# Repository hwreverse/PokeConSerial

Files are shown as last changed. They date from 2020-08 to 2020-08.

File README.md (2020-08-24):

# PokeConSerial
Serial Interfaces for Pocket Computers (ポケコン) (Sharp, Casio, TRS80-M100,...)<br>
(PCB Layouts are in KiCAD 5.1.6*)

- <a href="g850_kiss/">Sharp G800/G850/V/S/VS 11pin USB to Serial Interface</a>

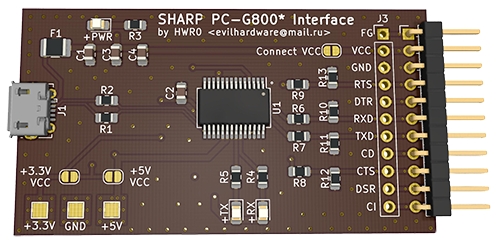
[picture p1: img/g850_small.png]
Sharp G850* USB to Serial Interface


- <a href="Sharp_11pin_to_15pin_Adapter/">Sharp 11pin to 15pin Adapter</a>
  (to use the Sharp G850* USB to Serial adapter with the Sharp PC-E500 and the Sharp PC-1600)
  
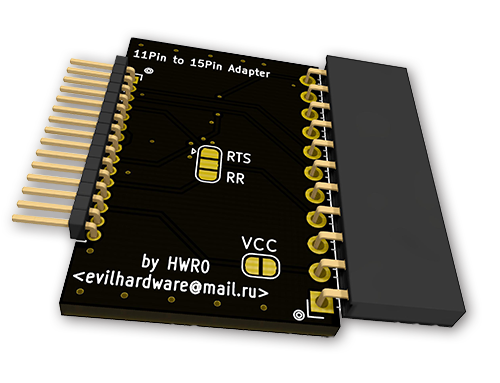
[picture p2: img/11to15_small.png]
Sharp 11pin to 15pin Adapter


- <a href="PC1600SIO/">Sharp PC-E500 / PC-1600 15pin USB to Serial Interface</a>
  
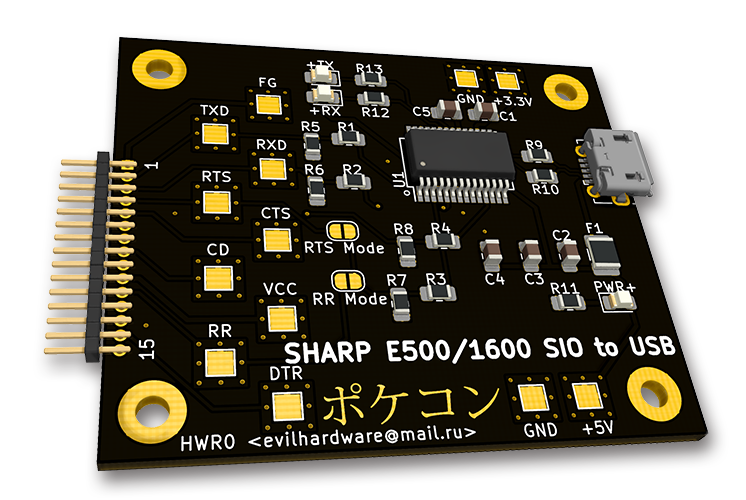
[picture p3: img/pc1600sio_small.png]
Sharp PC-E500 / PC-1600 15pin USB to Serial Interface


- Casio FA-7 compatible (for PB-1000, AI-1000, PB-2000C) USB Interface (soon, needs to be validated)

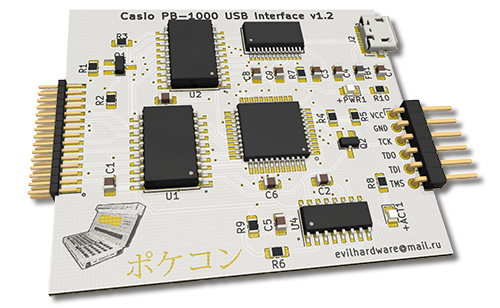
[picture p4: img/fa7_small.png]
Casio FA-7 compatible USB Interface


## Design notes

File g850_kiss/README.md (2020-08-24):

# SHARP PC-G800*/G850*/V/S/VS 11pin USB to Serial Interface
USB to Serial (FT232RL based) Interface for the SHARP G800* line of Pocket Computers (G811, G850, G850V, G850S, G850VS)

Sharp PC-G850* Adapter

## Important
NB1: the 11pin adapter is a 1x11 pin 2.54mm (100mil) male connector<br>
NB2: Use VCC Connect if for some reason, you want to power the device from USB (use with *EXTREME* care!!)<br>
NB3: Bridge the 5V VCCIO Solder Jumper to work with the G850*, this sets the I/O Level to 5V<br>

## Components

The USB-B-micro Receptacle in this schema is a Molex 105017-0001 / 105017-1001, every diode / R / C is 0805, FT232RL is a SSOP28, the Polyfuse is a 1210 500mA or similar

## After-Construction Configuration

As the Sharp Pocket computers use <b>inverted</b> Levels, you have to invert RXD, TXD, RTS# and CTS# on your FT232RL chip too.

You do this by downloading the program <b>FTProg</b> from the FTDI Site :  <a href="https://www.ftdichip.com/Support/Utilities.htm#FT_PROG">Here</a>.

You need also to configure CBUS0 as RXLED and CBUS1 as TXLED in order to gain LED Functionality.

<b> AND FOR HEAVENS' SAKE:</b> Never set the FT chip to External OSC (Escpecially on this board where it does not have an External Oscillator) lest you are self-destructive and want to brick your chip !

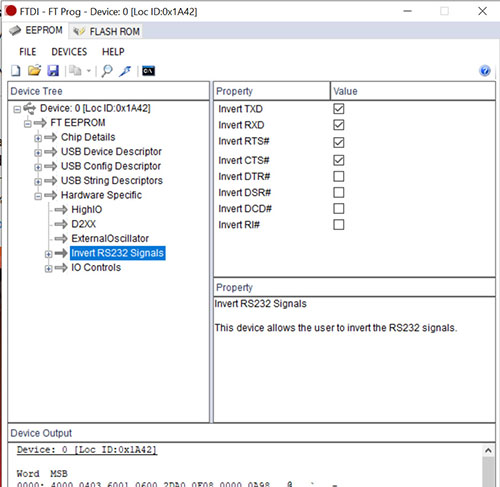
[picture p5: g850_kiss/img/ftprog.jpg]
ftprog


-------------------------

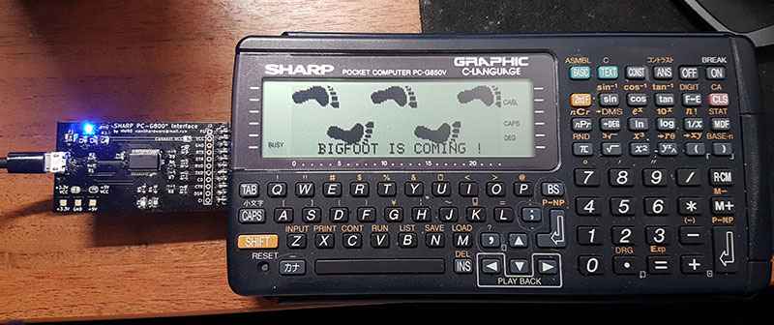
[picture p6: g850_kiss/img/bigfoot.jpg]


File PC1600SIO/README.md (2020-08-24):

# SHARP PC-E500/E500S/PC-1600/PC-1600K 15pin USB to Serial Interface
USB to Serial (FT232RL based) Interface for the SHARP PC-E500 / E500S / PC-1600 / PC-1600K line of Pocket Computers 

Sharp PC-E500/PC-1600 Adapter

## Important
NB 1: the 15pin adapter is a 1x15 pin 1.27mm (50mil) male connector<br>
NB 2: You have to bridge the right solderjumper (RR or RTS) depending on the mode you use for it to work. I have RTS bridged usually 

## Components

The USB-B-micro Receptacle in this schema is a Molex 105017-0001 / 105017-1001, every LED / R / L / C is 0805, FT232RL is a SSOP28, the Polyfuse is a 1210 PTC Resettable fuse, 500-700mA or similar

## After-Construction Configuration

As the Sharp Pocket computers use <b>inverted</b> Levels, you have to invert RXD, TXD, RTS# and CTS# on your FT232RL chip too.

You do this by downloading the program <b>FTProg</b> from the FTDI Site :  <a href="https://www.ftdichip.com/Support/Utilities.htm#FT_PROG">Here</a>.

You need also to configure CBUS0 as RXLED and CBUS1 as TXLED in order to gain LED Functionality.

<b> AND FOR HEAVEANS' SAKE:</b> Never set the FT chip to External OSC (Escpecially on this board where it does not have an External Oscillator) lest you are self-destructive and want to brick your chip !

ftprog

-------------------------

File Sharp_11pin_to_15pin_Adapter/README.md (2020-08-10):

# SHARP 11pin to 15pin Adapter
Adapter to use with the <a href="https://github.com/hwreverse/PokeConSerial/tree/master/g850_kiss">Sharp G800* USB to Serial Interface</a>
to make it work for the SHARP PC-E500 and the Sharp PC-1600

NB 1: the 11pin adapter is a 1x11 pin 2.54mm (100mil) female connector, the 15pin adaptor is a 1x15pin 1.27mm (50mil) male connector

NB 2: You have to bridge the right solderjumper (RR or RTS) depending on the mode you use for it to work. I use RTS with both calculators

NB 3: Use VCC Connect if for some reason, you want to power the device from USB (use with *EXTREME* care!!)

Sharp 11pin to 15pin adapter

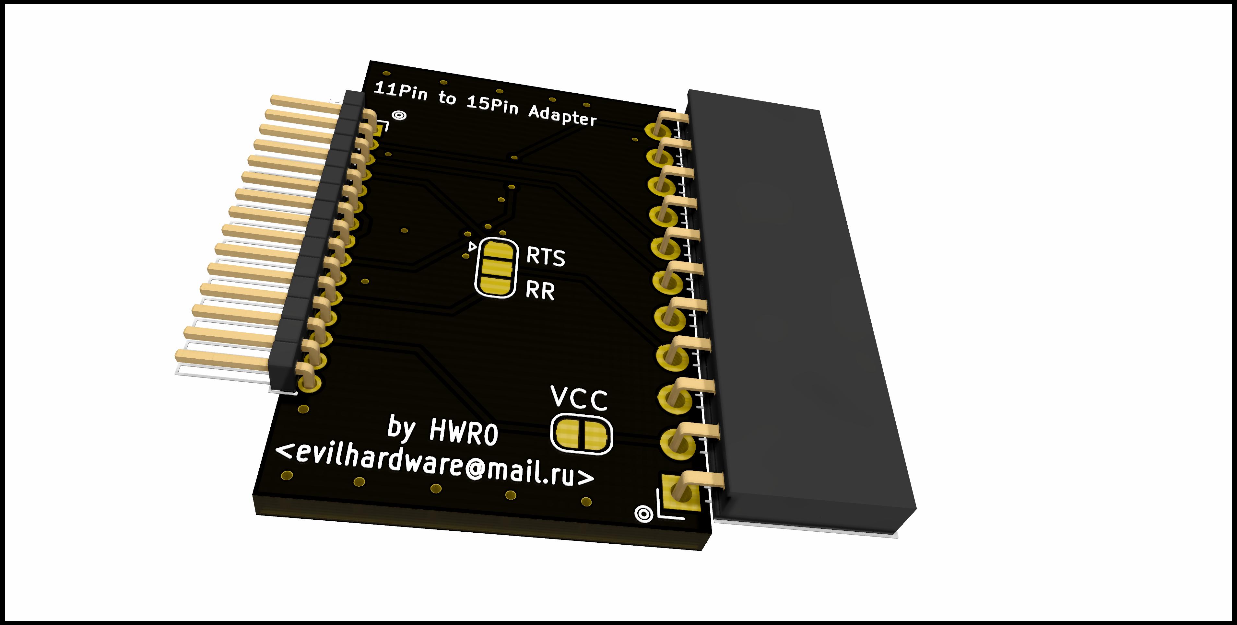
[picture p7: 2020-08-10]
Sharp_11pin_to_15pin_Adapter/Sharp_11pin_to_15pin_Adapter.jpg

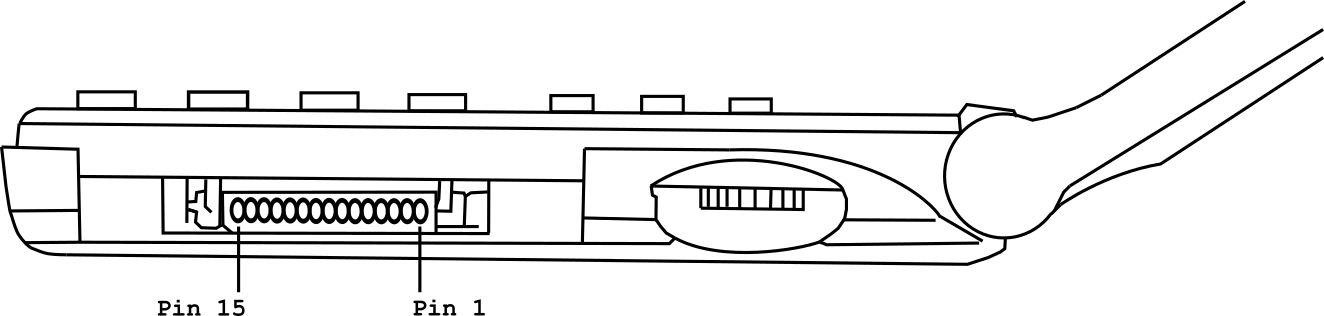
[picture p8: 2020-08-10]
PC1600SIO/e500sio.png

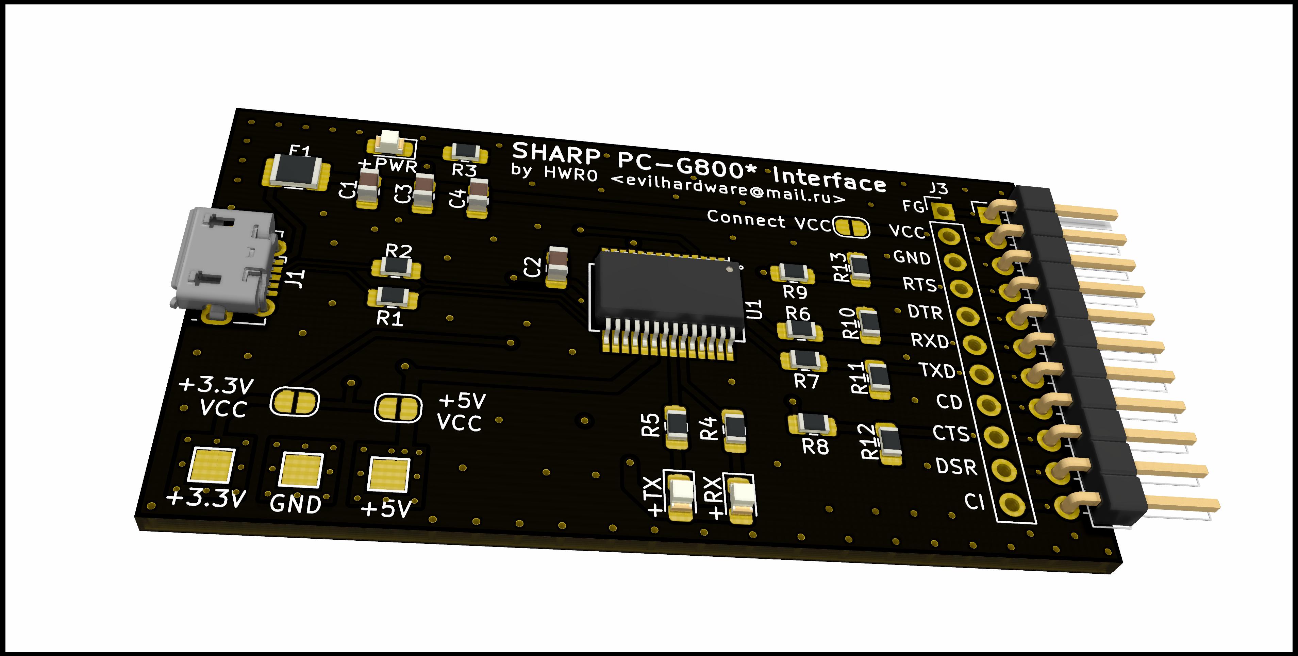
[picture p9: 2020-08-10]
g850_kiss/g850_kiss2.jpg

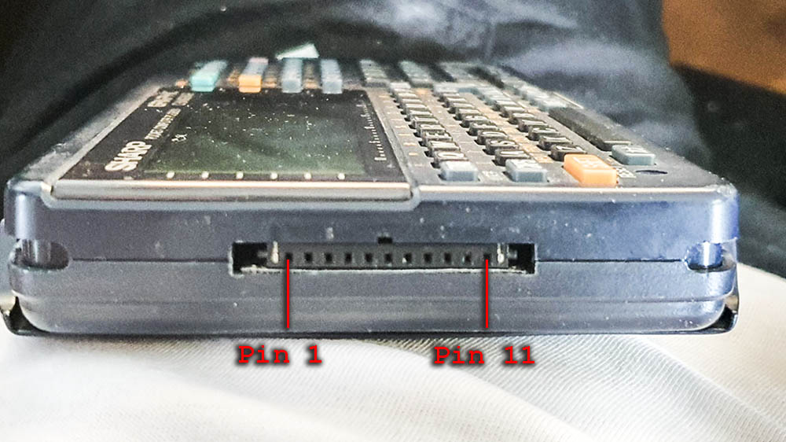
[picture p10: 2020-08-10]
g850_kiss/g850_11pin interface.jpg

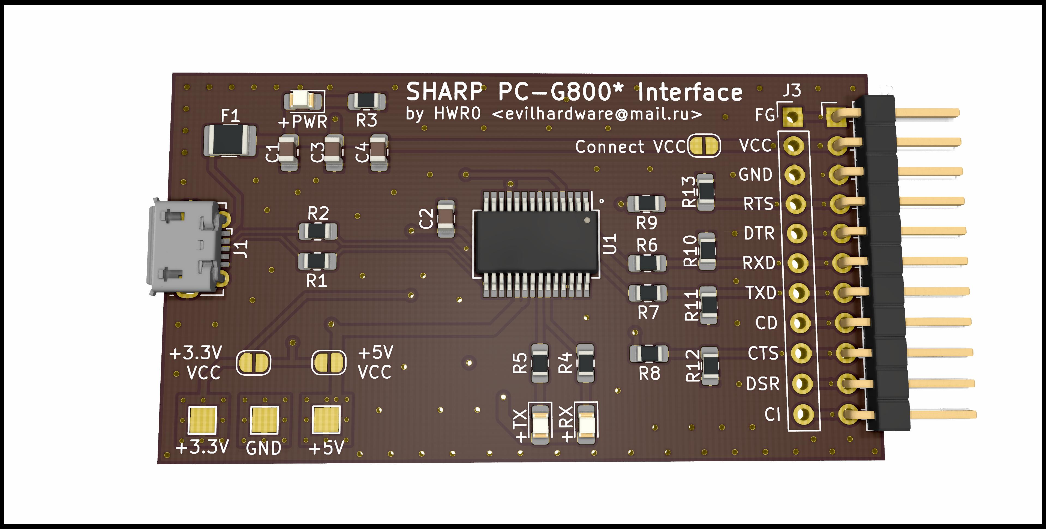
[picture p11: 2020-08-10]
g850_kiss/g850_kiss.jpg

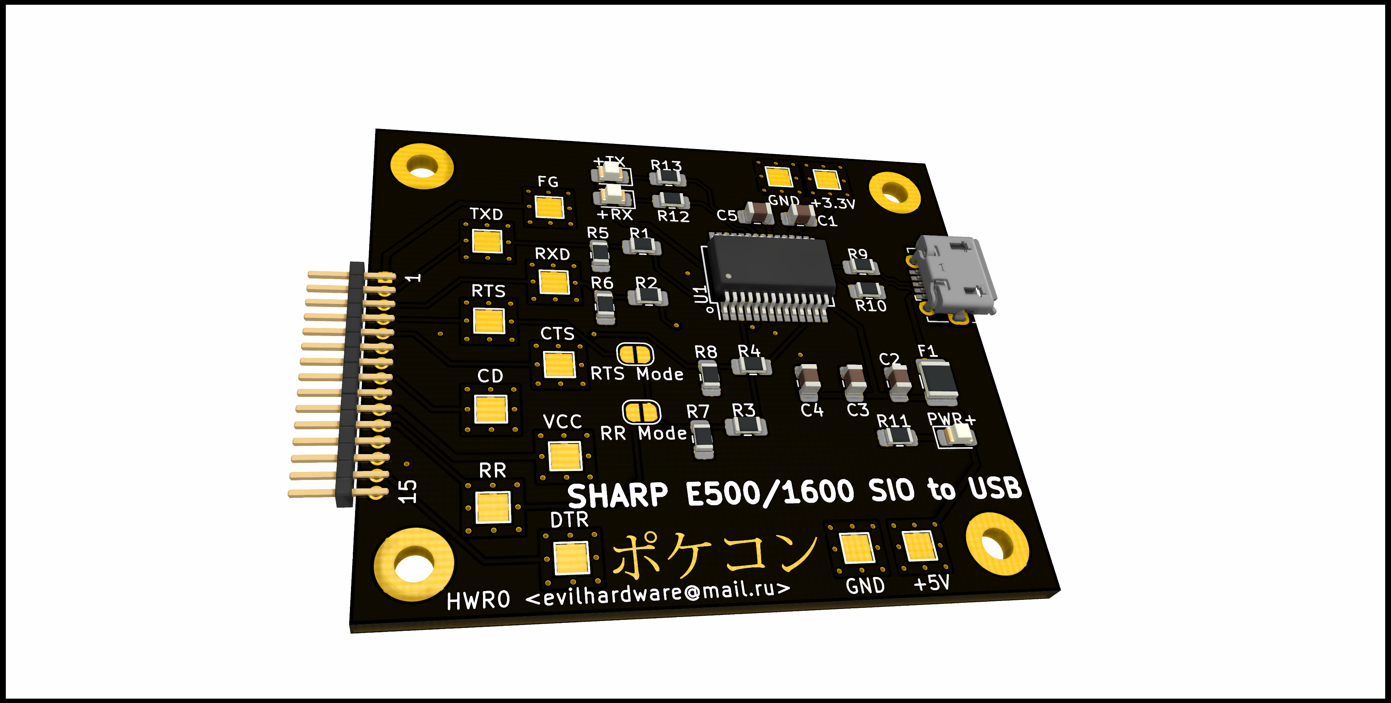
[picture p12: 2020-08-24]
PC1600SIO/PC1600SIO.png

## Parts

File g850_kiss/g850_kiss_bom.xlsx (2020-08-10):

Source: | O:\elec\g850_kiss\g850_kiss.sch
Date: | 2019-12-28 15:27
Tool: | Eeschema (5.1.5)-3
Component Count: | 28
Ref | Value | Footprint | Datasheet | Manufacturer | Vendor
C1 | 0.1uF | Capacitor_SMD:C_0805_2012Metric_Pad1.15x1.40mm_HandSolder | ~
C2 | 0.1uF | Capacitor_SMD:C_0805_2012Metric_Pad1.15x1.40mm_HandSolder | ~
C3 | 10nF | Capacitor_SMD:C_0805_2012Metric_Pad1.15x1.40mm_HandSolder | ~
C4 | 10nF | Capacitor_SMD:C_0805_2012Metric_Pad1.15x1.40mm_HandSolder | ~
D1 | PWRLED | LED_SMD:LED_0805_2012Metric_Pad1.15x1.40mm_HandSolder | ~
D2 | RX | LED_SMD:LED_0805_2012Metric_Pad1.15x1.40mm_HandSolder | ~
D3 | TX | LED_SMD:LED_0805_2012Metric_Pad1.15x1.40mm_HandSolder | ~
F1 | Polyfuse 1210 | Resistor_SMD:R_1210_3225Metric_Pad1.42x2.65mm_HandSolder | 500mA polyfuse (1210)
J1 | USB_B_Micro | hwreverse:USB_Micro-B_Molex-105017-0001 | Molex-105017-0001 USB micro
J2 | G850_Input_Connector | Connector_PinHeader_2.54mm:PinHeader_1x11_P2.54mm_Horizontal | ~
J3 | Dup_G850_Connector | Connector_PinHeader_2.54mm:PinHeader_1x11_P2.54mm_Vertical | ~
JP1 | SJ3V | Jumper:SolderJumper-2_P1.3mm_Open_RoundedPad1.0x1.5mm | ~
JP2 | SJ5V | Jumper:SolderJumper-2_P1.3mm_Open_RoundedPad1.0x1.5mm | ~
JP3 | SJPWRCalc | Jumper:SolderJumper-2_P1.3mm_Open_RoundedPad1.0x1.5mm | ~
R1 | 15R | Resistor_SMD:R_0805_2012Metric_Pad1.15x1.40mm_HandSolder | ~
R2 | 15R | Resistor_SMD:R_0805_2012Metric_Pad1.15x1.40mm_HandSolder | ~
R3 | 500R | Resistor_SMD:R_0805_2012Metric_Pad1.15x1.40mm_HandSolder | ~
R4 | 500R | Resistor_SMD:R_0805_2012Metric_Pad1.15x1.40mm_HandSolder | ~
R5 | 500R | Resistor_SMD:R_0805_2012Metric_Pad1.15x1.40mm_HandSolder | ~
R6 | 100R | Resistor_SMD:R_0805_2012Metric_Pad1.15x1.40mm_HandSolder | ~
R7 | 100R | Resistor_SMD:R_0805_2012Metric_Pad1.15x1.40mm_HandSolder | ~
R8 | 100R | Resistor_SMD:R_0805_2012Metric_Pad1.15x1.40mm_HandSolder | ~
R9 | 100R | Resistor_SMD:R_0805_2012Metric_Pad1.15x1.40mm_HandSolder | ~
R10 | 10K | Resistor_SMD:R_0805_2012Metric_Pad1.15x1.40mm_HandSolder | ~
R11 | 10K | Resistor_SMD:R_0805_2012Metric_Pad1.15x1.40mm_HandSolder | ~
R12 | 10K | Resistor_SMD:R_0805_2012Metric_Pad1.15x1.40mm_HandSolder | ~
R13 | 10K | Resistor_SMD:R_0805_2012Metric_Pad1.15x1.40mm_HandSolder | ~
U1 | FT232RL | Package_SO:SSOP-28_5.3x10.2mm_P0.65mm | https://www.ftdichip.com/Support/Documents/DataSheets/ICs/DS_FT232R.pdf

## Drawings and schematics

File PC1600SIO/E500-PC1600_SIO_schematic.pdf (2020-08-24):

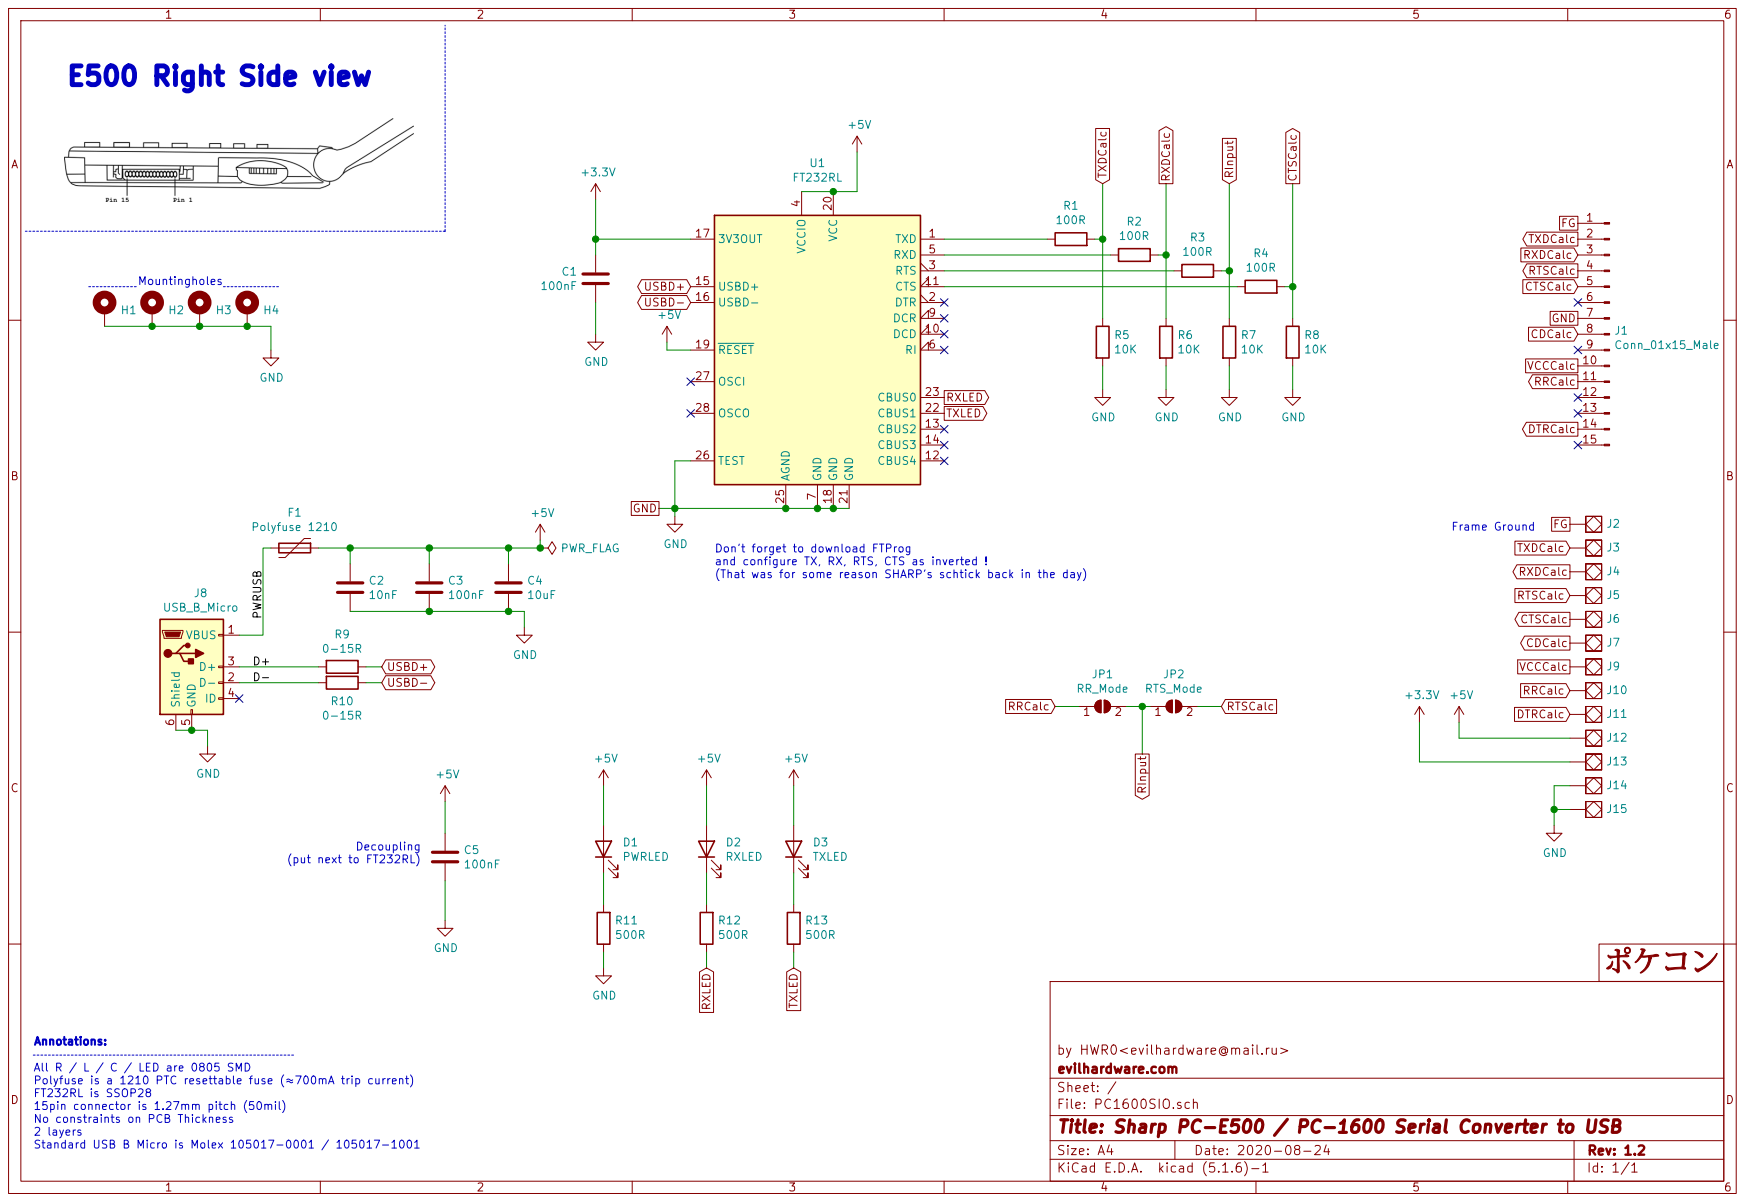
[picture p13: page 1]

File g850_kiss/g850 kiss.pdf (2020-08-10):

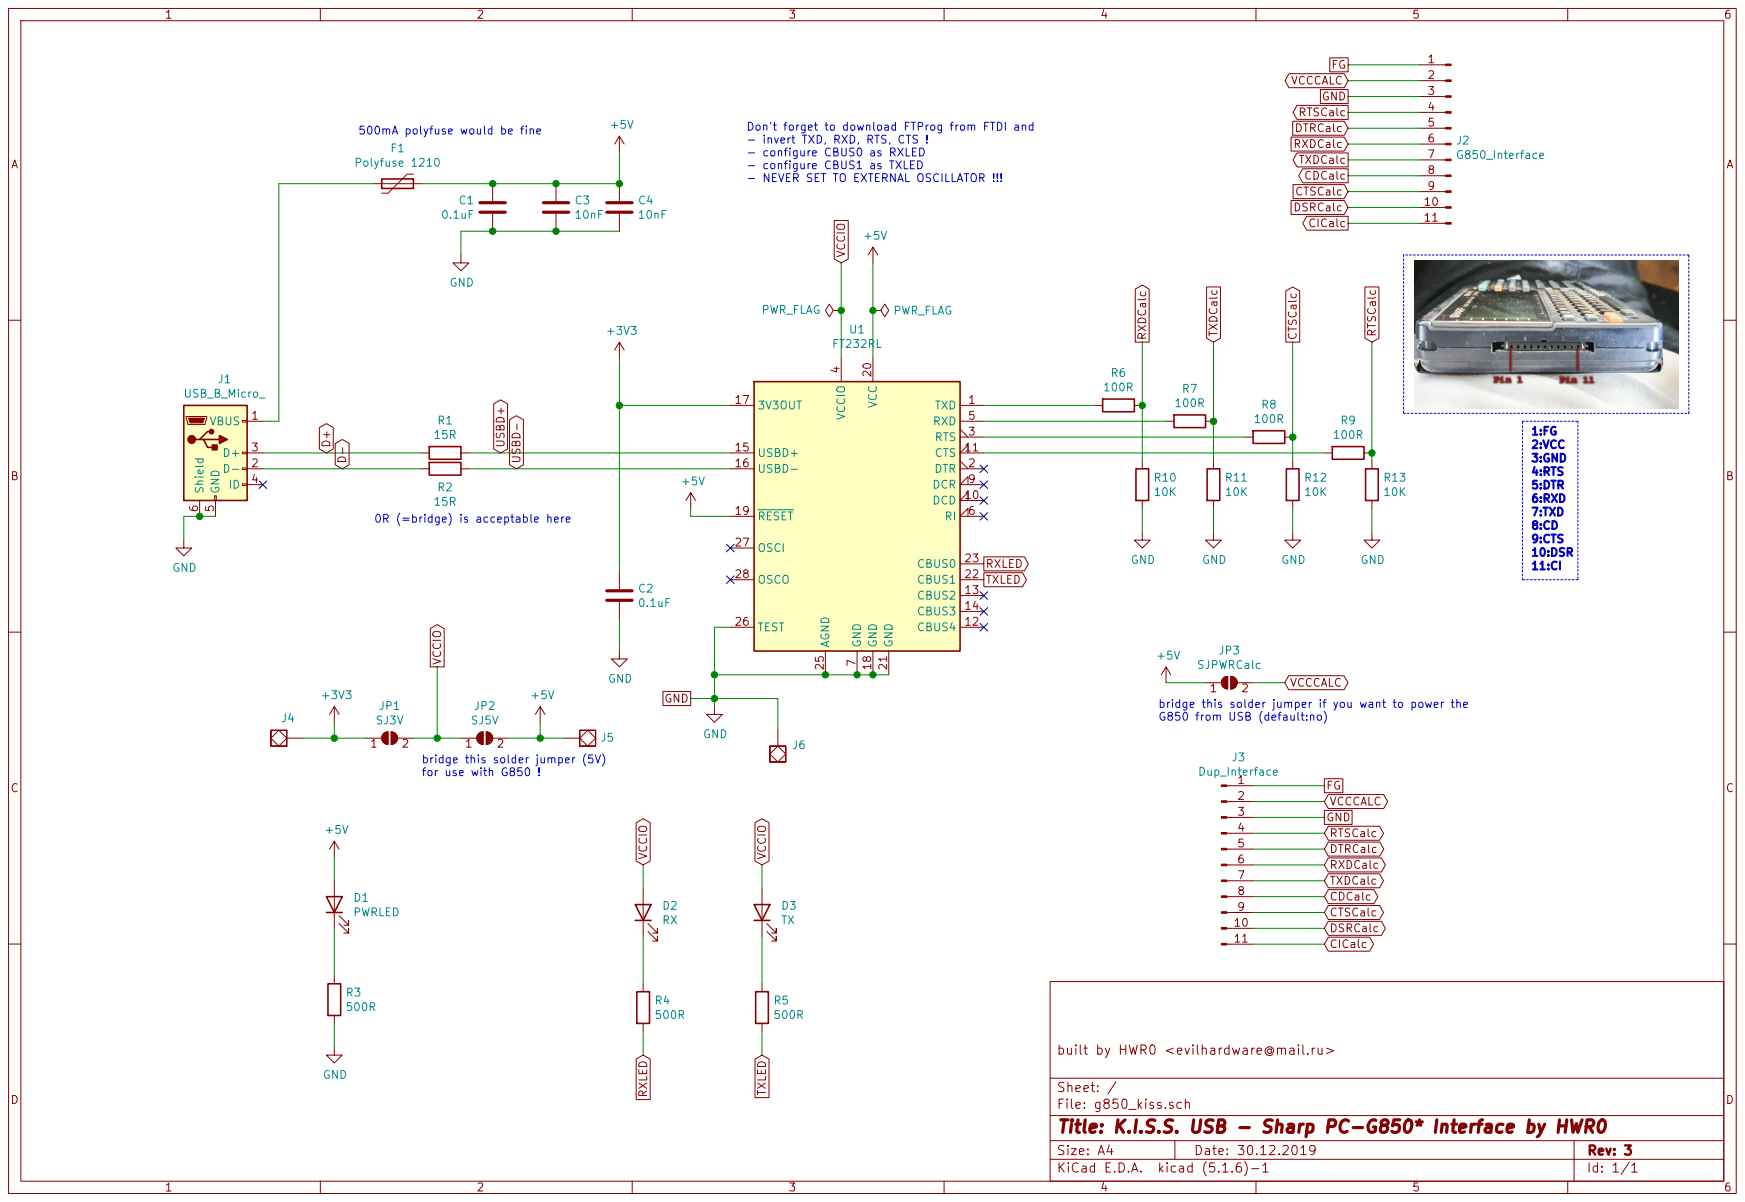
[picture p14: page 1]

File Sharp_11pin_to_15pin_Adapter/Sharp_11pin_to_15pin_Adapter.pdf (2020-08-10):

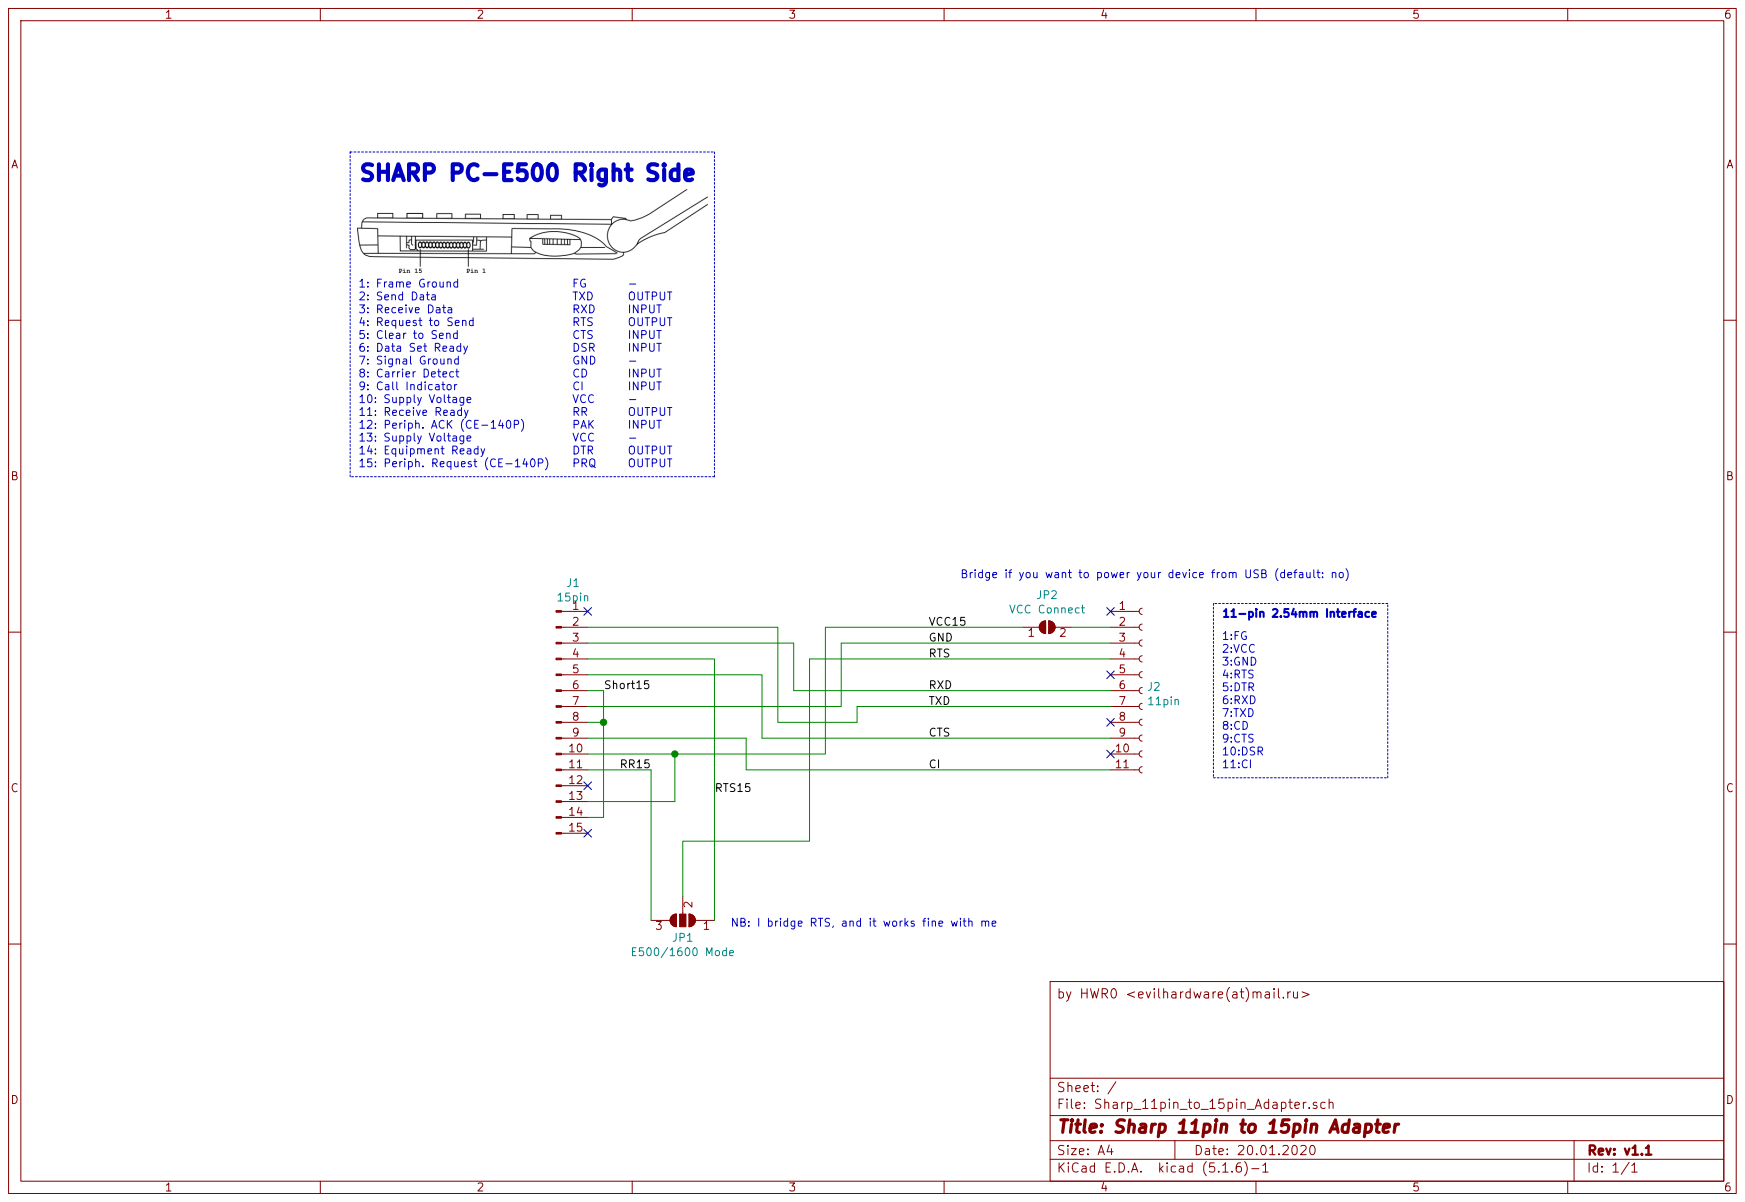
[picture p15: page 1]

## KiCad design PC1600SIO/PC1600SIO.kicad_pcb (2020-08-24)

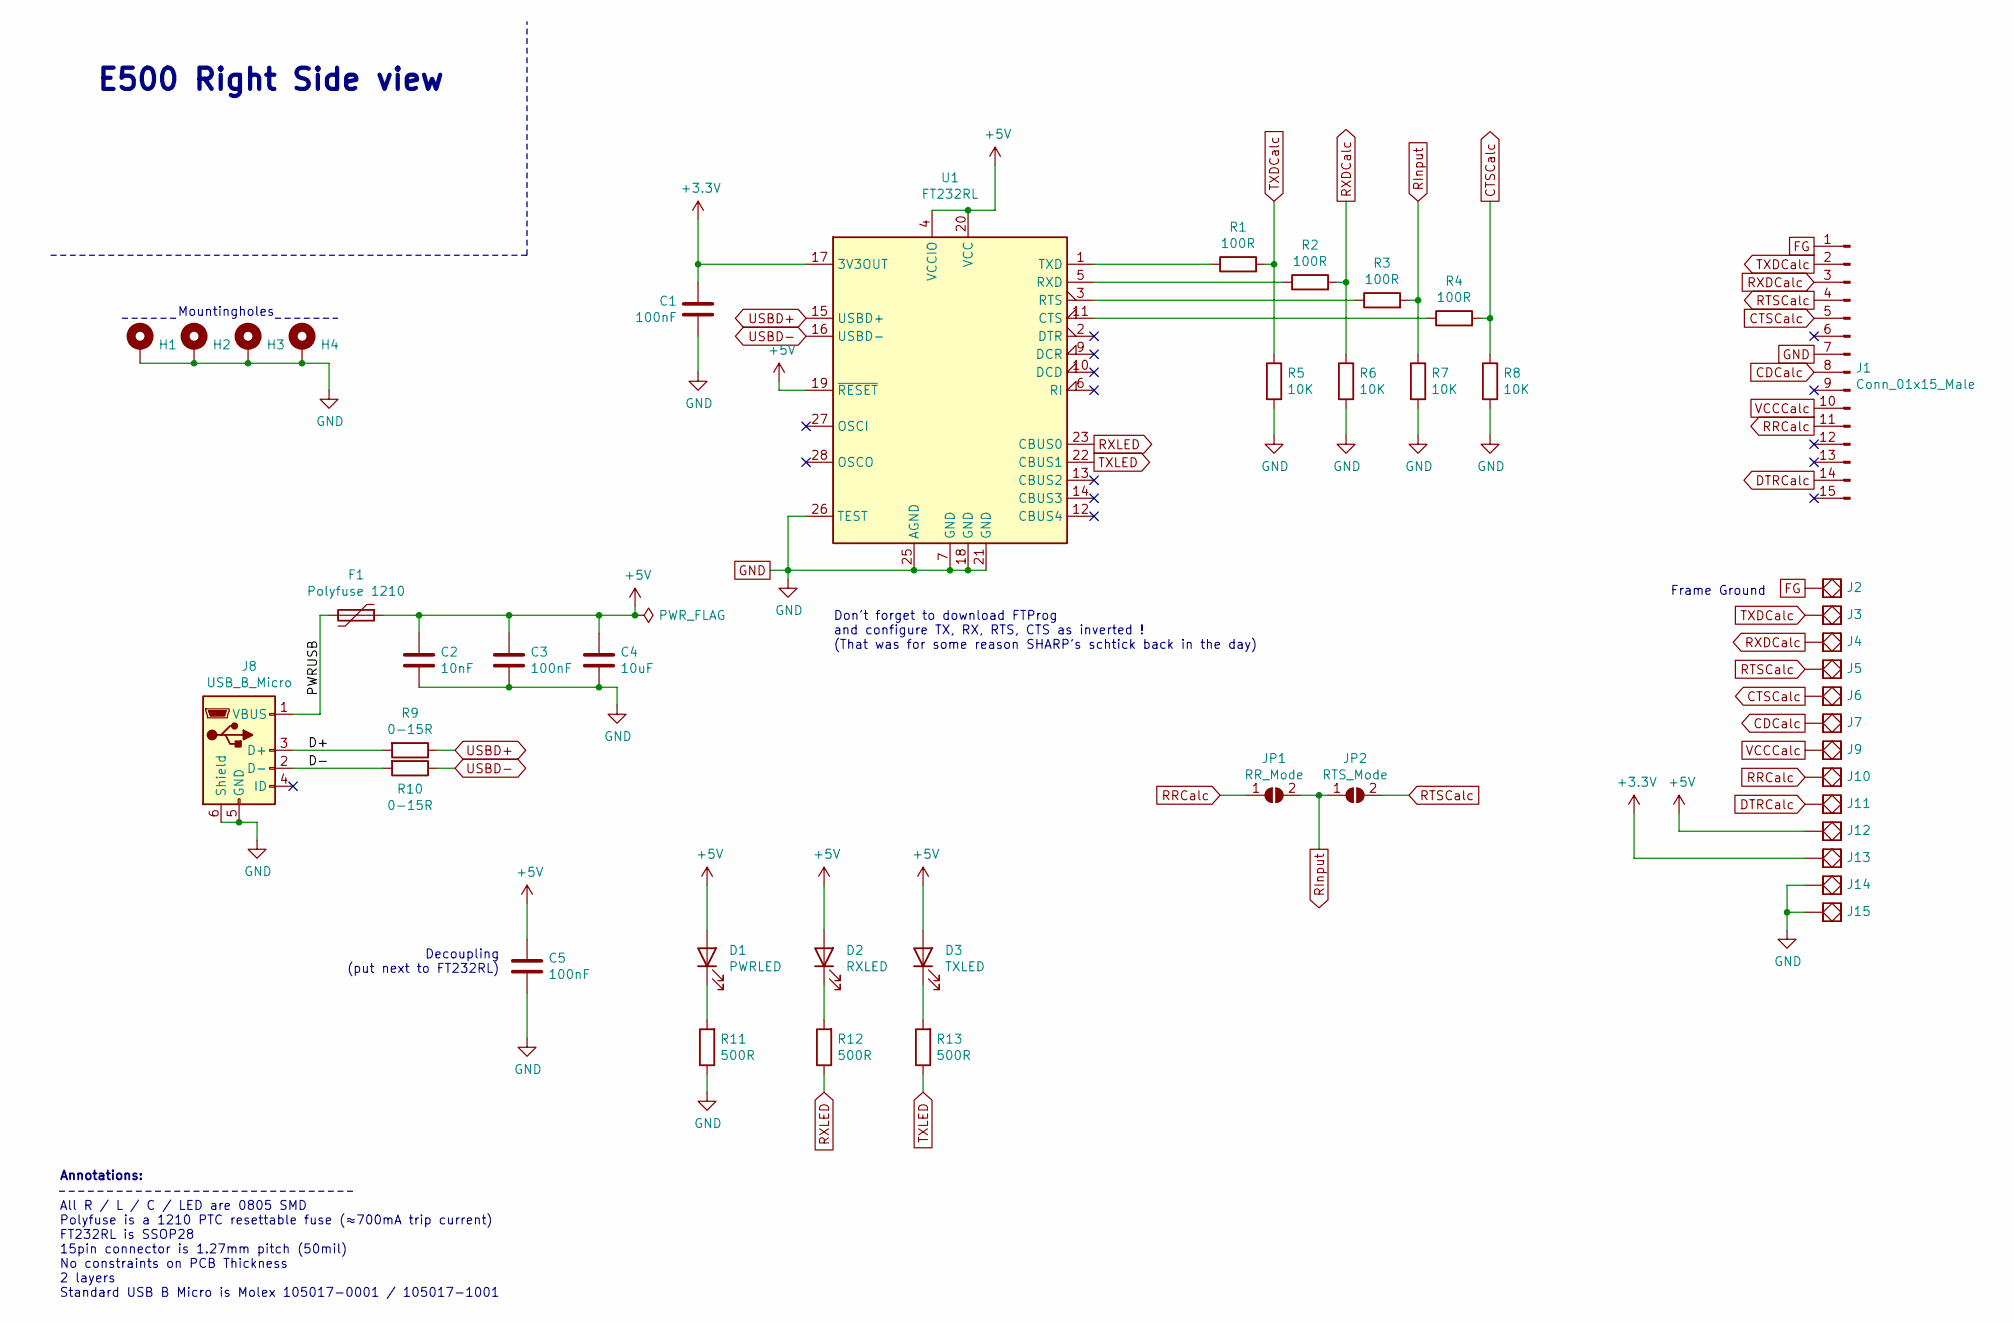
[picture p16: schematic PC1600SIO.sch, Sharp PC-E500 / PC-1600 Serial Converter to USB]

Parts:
C1, C3, C5: 100nF; C_0805_2012Metric_Pad1.15x1.40mm_HandSolder
C2: 10nF; C_0805_2012Metric_Pad1.15x1.40mm_HandSolder
C4: 10uF; C_0805_2012Metric_Pad1.15x1.40mm_HandSolder
D1: PWRLED; LED_0805_2012Metric_Pad1.15x1.40mm_HandSolder
D2: RXLED; LED_0805_2012Metric_Pad1.15x1.40mm_HandSolder
D3: TXLED; LED_0805_2012Metric_Pad1.15x1.40mm_HandSolder
F1: Polyfuse 1210; R_1210_3225Metric_Pad1.42x2.65mm_HandSolder
H1, H2, H3, H4: MountingHole_Pad; MountingHole_2.5mm_Pad
J1: Conn_01x15_Male; PinHeader_1x15_P1.27mm_Vertical
J2, J3, J4, J5, J6, J7, J9, J10, J11, J12, J13, J14, J15: SolidPad-Connector; SolidPad_4x4mm_2x2mmCore
J8: USB_B_Micro; USB_Micro-B_Molex-105017-0001
JP1: RR_Mode; SolderJumper-2_P1.3mm_Open_RoundedPad1.0x1.5mm
JP2: RTS_Mode; SolderJumper-2_P1.3mm_Open_RoundedPad1.0x1.5mm
R1, R2, R3, R4: 100R; R_0805_2012Metric_Pad1.15x1.40mm_HandSolder
R5, R6, R7, R8: 10K; R_0805_2012Metric_Pad1.15x1.40mm_HandSolder
R9, R10: 0-15R; R_0805_2012Metric_Pad1.15x1.40mm_HandSolder
R11, R12, R13: 500R; R_0805_2012Metric_Pad1.15x1.40mm_HandSolder
U1: FT232RL; SSOP-28_5.3x10.2mm_P0.65mm

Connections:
+3V3: C1.1, J13.~, U1.17 (3V3OUT)
+5V: C2.1, C3.1, C4.1, C5.1, D1.2 (A), D2.2 (A), D3.2 (A), F1.1, J12.~, U1.4 (VCCIO), U1.19 (~RESET~), U1.20 (VCC)
/D+: J8.3 (D+), R9.2
/D-: J8.2 (D-), R10.2
/PWRUSB: F1.2, J8.1 (VBUS)
CDCalc: J1.8, J7.~
CTSCalc: J1.5, J6.~, R4.2, R8.1
DTRCalc: J1.14, J11.~
FG: J1.1, J2.~
GND: C1.2, C2.2, C3.2, C4.2, C5.2, H1.1, H2.1, H3.1, H4.1, J1.7, J8.5 (GND), J8.6 (Shield), J14.~, J15.~, R5.2, R6.2, R7.2, R8.2, R11.1, U1.7 (GND), U1.18 (GND), U1.21 (GND), U1.25 (AGND), U1.26 (TEST)
unnamed: D1.1 (K), R11.2
unnamed: D2.1 (K), R12.2
unnamed: D3.1 (K), R13.2
unnamed: R1.1, U1.1 (TXD)
unnamed: R2.1, U1.5 (RXD)
unnamed: R3.1, U1.3 (RTS)
unnamed: R4.1, U1.11 (CTS)
RInput: JP1.2 (B), JP2.1 (A), R3.2, R7.1
RRCalc: J1.11, J10.~, JP1.1 (A)
RTSCalc: J1.4, J5.~, JP2.2 (B)
RXDCalc: J1.3, J4.~, R2.2, R6.1
RXLED: R12.1, U1.23 (CBUS0)
TXDCalc: J1.2, J3.~, R1.2, R5.1
TXLED: R13.1, U1.22 (CBUS1)
USBD+: R9.1, U1.15 (USBD+)
USBD-: R10.1, U1.16 (USBD-)
VCCCalc: J1.10, J9.~

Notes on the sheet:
E500 Right Side view
Mountingholes
All R / L / C / LED are 0805 SMD Polyfuse is a 1210 PTC resettable fuse (≈700mA trip current) FT232RL is SSOP28 15pin connector is 1.27mm pitch (50mil) No constraints on PCB Thickness 2 layers Standard USB B Micro is Molex 105017-0001 / 105017-1001
Annotations:
Decoupling (put next to FT232RL)
Frame Ground
Don't forget to download FTProg and configure TX, RX, RTS, CTS as inverted ! (That was for some reason SHARP's schtick back in the day)

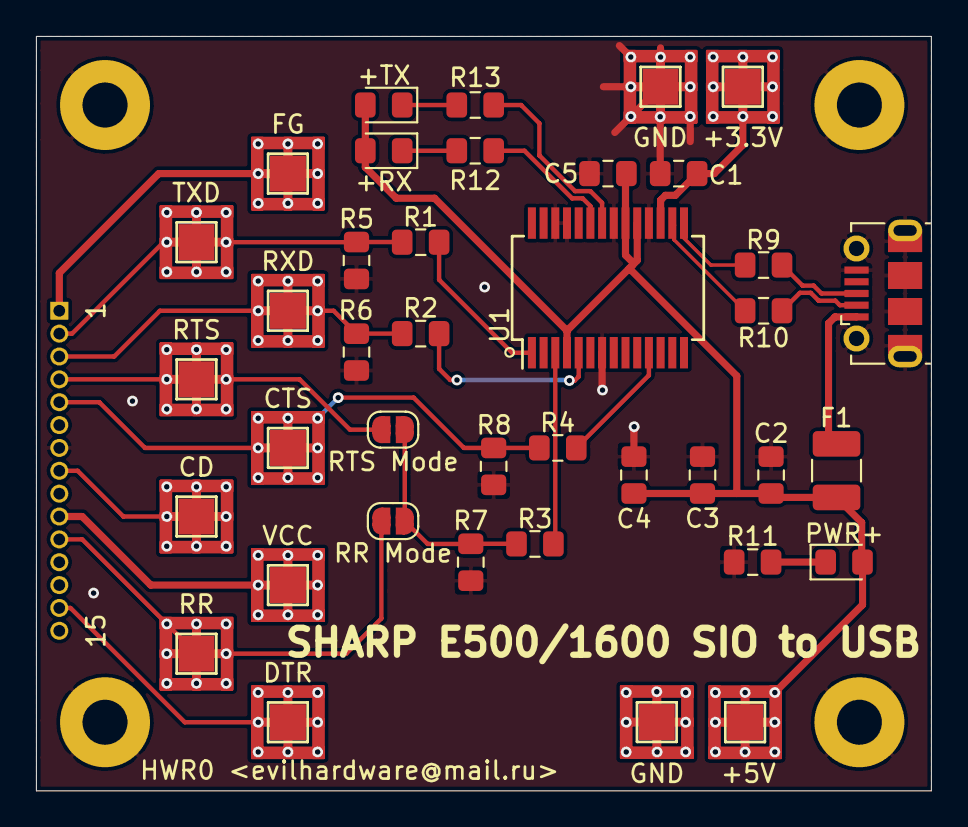
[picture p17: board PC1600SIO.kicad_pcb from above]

Board: 2 copper layers, 49.7 x 41.9 mm, 44 parts (0 on the bottom side), 27 nets.

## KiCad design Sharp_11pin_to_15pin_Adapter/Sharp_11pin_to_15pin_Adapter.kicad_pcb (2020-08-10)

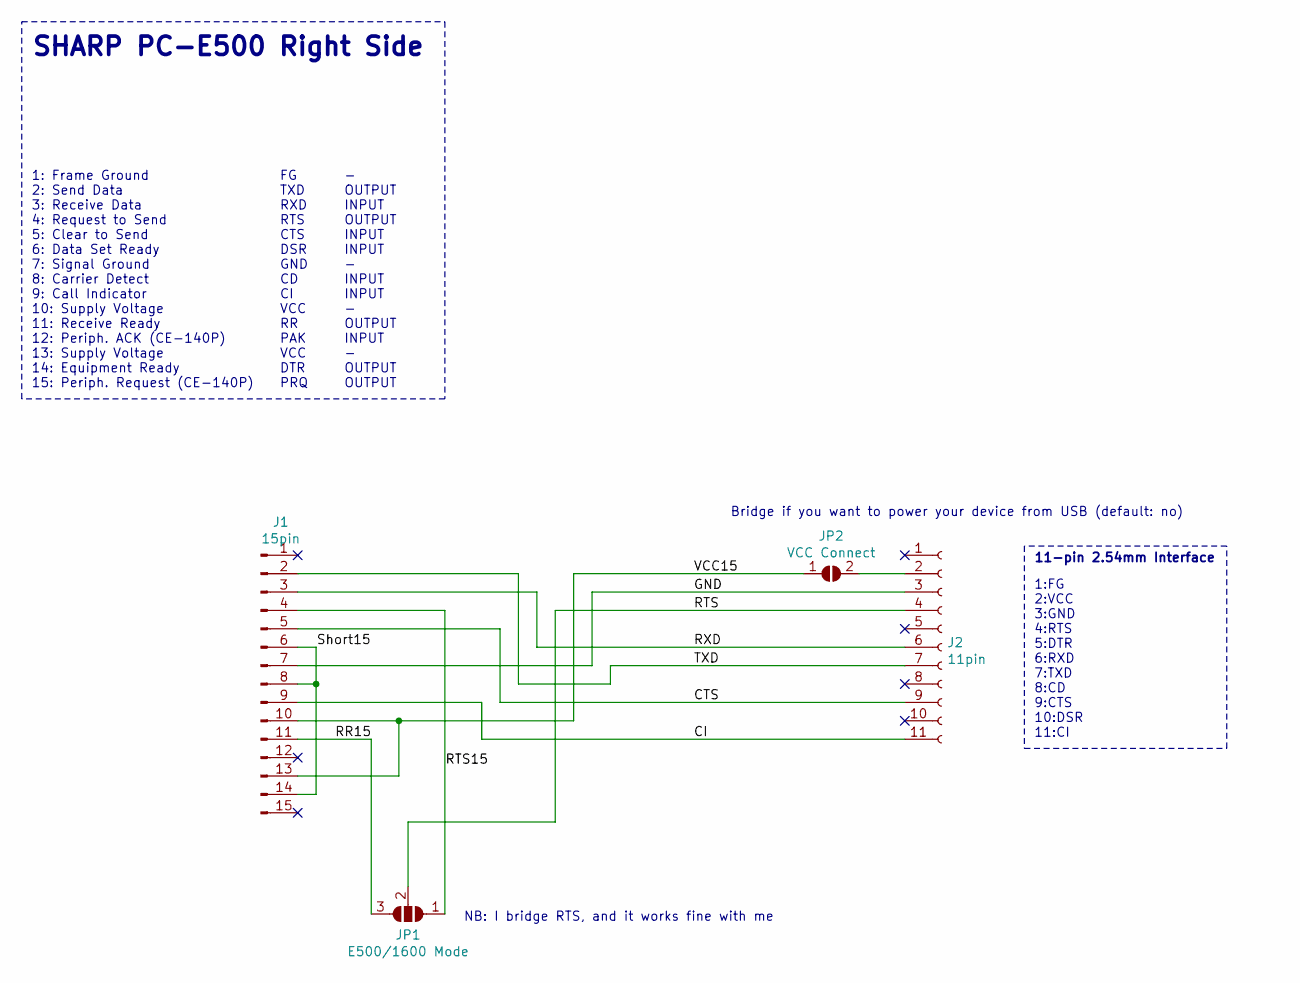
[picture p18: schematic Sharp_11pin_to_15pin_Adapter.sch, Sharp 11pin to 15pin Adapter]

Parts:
J1: 15pin; PinHeader_1x15_P1.27mm_Horizontal_mirror
J2: 11pin; PinSocket_1x11_P2.54mm_Horizontal-mirror
JP1: E500/1600 Mode; SolderJumper-3_P1.3mm_Open_RoundedPad1.0x1.5mm
JP2: VCC Connect; SolderJumper-2_P1.3mm_Open_RoundedPad1.0x1.5mm

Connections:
/CI: J1.9, J2.11
/CTS: J1.5, J2.9
/GND: J1.7, J2.3
/RR15: J1.11, JP1.3 (B)
/RTS: J2.4, JP1.2 (C)
/RTS15: J1.4, JP1.1 (A)
/RXD: J1.3, J2.6
/Short15: J1.6, J1.8, J1.14
/TXD: J1.2, J2.7
/VCC15: J1.10, J1.13, JP2.1 (A)
unnamed: J2.2, JP2.2 (B)

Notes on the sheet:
1:FG 2:VCC 3:GND 4:RTS 5:DTR 6:RXD 7:TXD 8:CD 9:CTS 10:DSR 11:CI
11-pin 2.54mm Interface
1: Frame Ground 2: Send Data 3: Receive Data 4: Request to Send 5: Clear to Send 6: Data Set Ready 7: Signal Ground 8: Carrier Detect 9: Call Indicator 10: Supply Voltage 11: Receive Ready 12: Periph. ACK (CE-140P) 13: Supply Voltage 14: Equipment Ready 15: Periph. Request (CE-140P)
FG TXD RXD RTS CTS DSR GND CD CI VCC RR PAK VCC DTR PRQ
- OUTPUT INPUT OUTPUT INPUT INPUT - INPUT INPUT - OUTPUT INPUT - OUTPUT OUTPUT
SHARP PC-E500 Right Side
NB: I bridge RTS, and it works fine with me
Bridge if you want to power your device from USB (default: no)

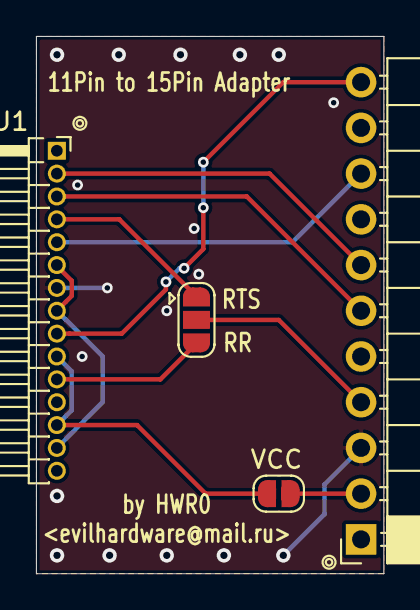
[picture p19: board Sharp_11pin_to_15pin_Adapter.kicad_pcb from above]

Board: 2 copper layers, 19.3 x 29.8 mm, 4 parts (0 on the bottom side), 11 nets.

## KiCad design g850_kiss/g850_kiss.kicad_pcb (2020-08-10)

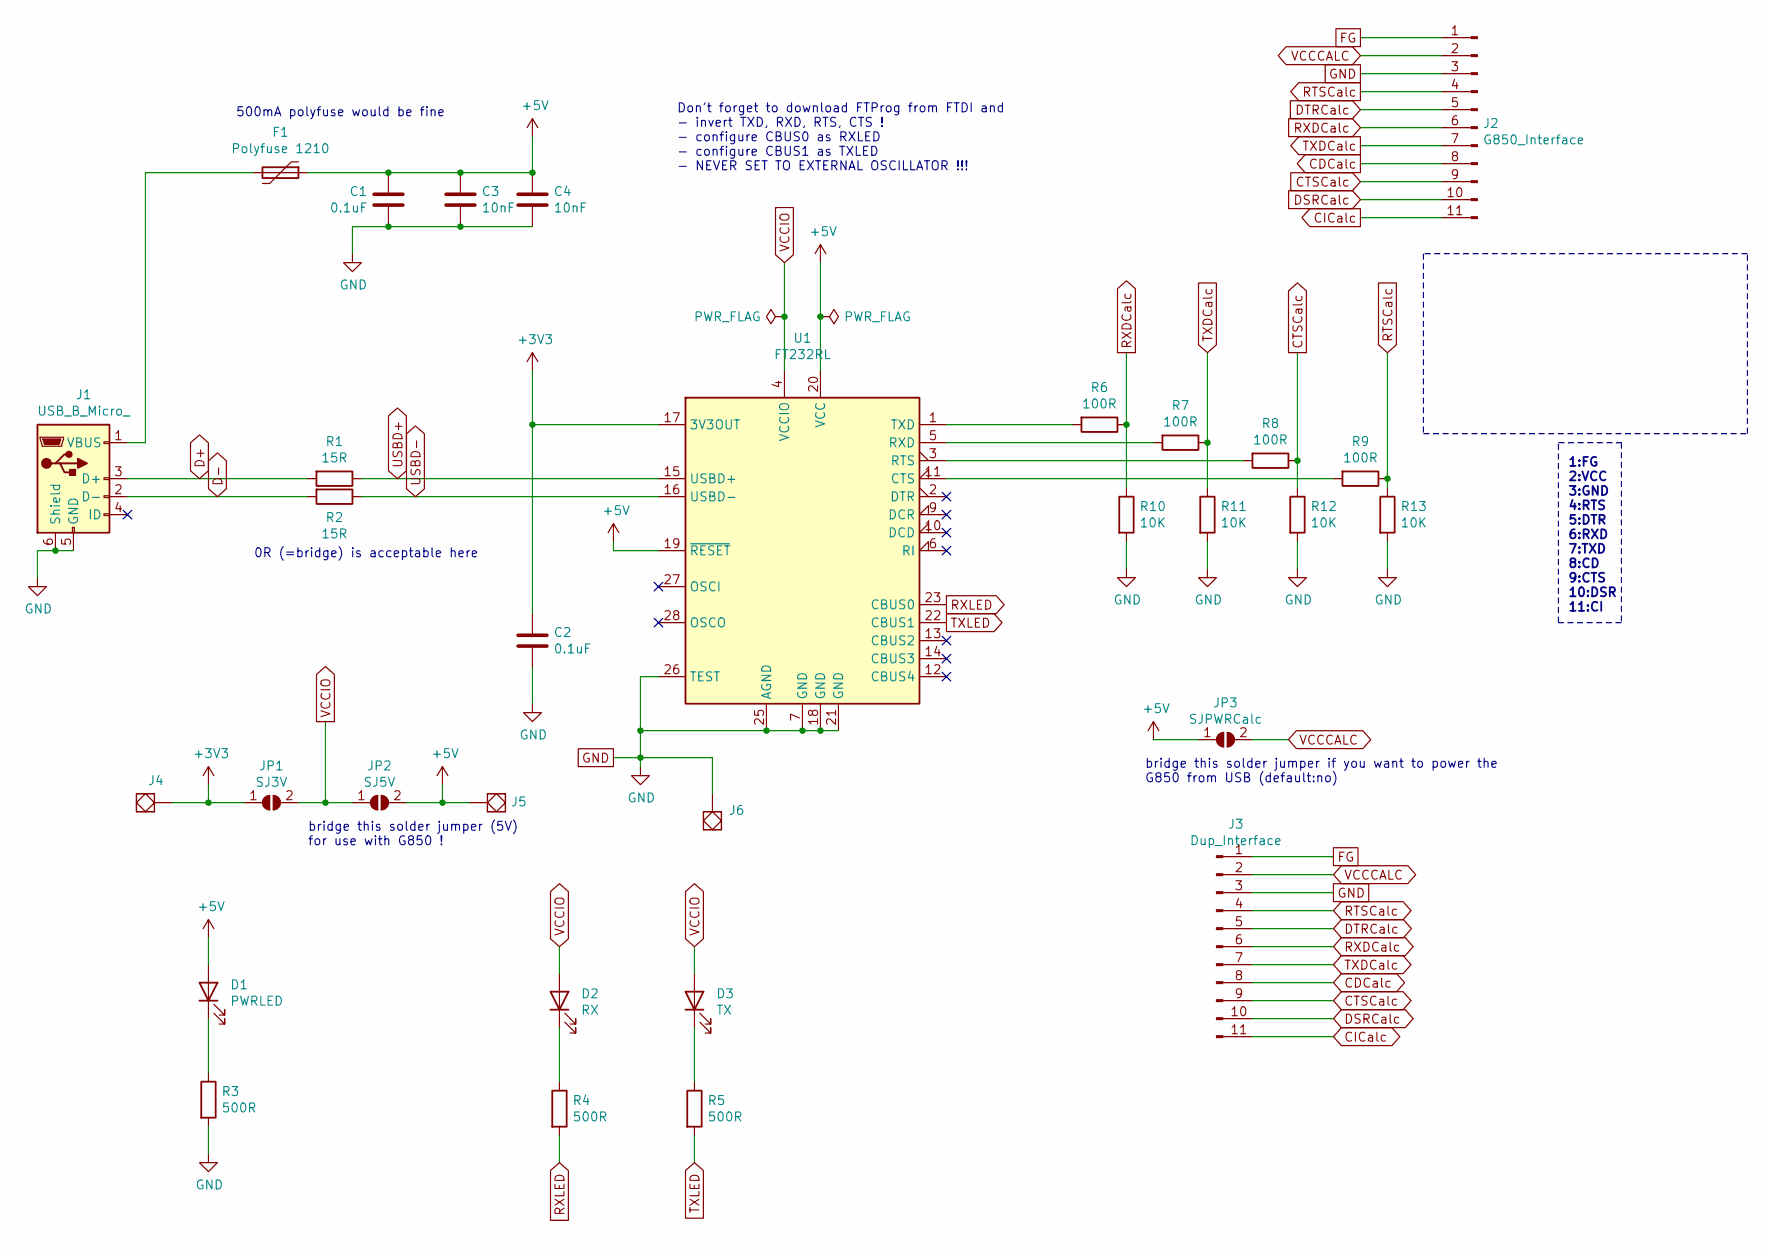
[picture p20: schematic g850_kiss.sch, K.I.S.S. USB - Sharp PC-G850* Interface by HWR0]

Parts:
C1, C2: 0.1uF; C_0805_2012Metric_Pad1.15x1.40mm_HandSolder
C3, C4: 10nF; C_0805_2012Metric_Pad1.15x1.40mm_HandSolder
D1: PWRLED; LED_0805_2012Metric_Pad1.15x1.40mm_HandSolder
D2: RX; LED_0805_2012Metric_Pad1.15x1.40mm_HandSolder
D3: TX; LED_0805_2012Metric_Pad1.15x1.40mm_HandSolder
F1: Polyfuse 1210; R_1210_3225Metric_Pad1.42x2.65mm_HandSolder
J1: USB_B_Micro_; USB_Micro-B_Molex-105017-0001
J2: G850_Interface; PinHeader_1x11_P2.54mm_Horizontal
J3: Dup_Interface; PinHeader_1x11_P2.54mm_Vertical
J4, J5, J6: SolidPad-Connector; SolidPad_4x4mm_2x2mmCore
JP1: SJ3V; SolderJumper-2_P1.3mm_Open_RoundedPad1.0x1.5mm
JP2: SJ5V; SolderJumper-2_P1.3mm_Open_RoundedPad1.0x1.5mm
JP3: SJPWRCalc; SolderJumper-2_P1.3mm_Open_RoundedPad1.0x1.5mm
R1, R2: 15R; R_0805_2012Metric_Pad1.15x1.40mm_HandSolder
R3, R4, R5: 500R; R_0805_2012Metric_Pad1.15x1.40mm_HandSolder
R6, R7, R8, R9: 100R; R_0805_2012Metric_Pad1.15x1.40mm_HandSolder
R10, R11, R12, R13: 10K; R_0805_2012Metric_Pad1.15x1.40mm_HandSolder
U1: FT232RL; SSOP-28_5.3x10.2mm_P0.65mm

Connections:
+3V3: C2.1, J4.~, JP1.1 (A), U1.17 (3V3OUT)
+5V: C1.1, C3.1, C4.1, D1.2 (A), F1.1, J5.~, JP2.2 (B), JP3.1 (A), U1.19 (~RESET~), U1.20 (VCC)
CDCalc: J2.8, J3.8
CICalc: J2.11, J3.11
CTSCalc: J2.9, J3.9, R8.1, R12.1
D+: J1.3 (D+), R1.2
D-: J1.2 (D-), R2.2
DSRCalc: J2.10, J3.10
DTRCalc: J2.5, J3.5
FG: J2.1, J3.1
GND: C1.2, C2.2, C3.2, C4.2, J1.5 (GND), J1.6 (Shield), J2.3, J3.3, J6.~, R3.2, R10.2, R11.2, R12.2, R13.2, U1.7 (GND), U1.18 (GND), U1.21 (GND), U1.25 (AGND), U1.26 (TEST)
unnamed: D1.1 (K), R3.1
unnamed: D2.1 (K), R4.1
unnamed: D3.1 (K), R5.1
unnamed: F1.2, J1.1 (VBUS)
unnamed: R6.2, U1.1 (TXD)
unnamed: R7.2, U1.5 (RXD)
unnamed: R8.2, U1.3 (RTS)
unnamed: R9.2, U1.11 (CTS)
RTSCalc: J2.4, J3.4, R9.1, R13.1
RXDCalc: J2.6, J3.6, R6.1, R10.1
RXLED: R4.2, U1.23 (CBUS0)
TXDCalc: J2.7, J3.7, R7.1, R11.1
TXLED: R5.2, U1.22 (CBUS1)
USBD+: R1.1, U1.15 (USBD+)
USBD-: R2.1, U1.16 (USBD-)
VCCCALC: J2.2, J3.2, JP3.2 (B)
VCCIO: D2.2 (A), D3.2 (A), JP1.2 (B), JP2.1 (A), U1.4 (VCCIO)

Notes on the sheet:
1:FG 2:VCC 3:GND 4:RTS 5:DTR 6:RXD 7:TXD 8:CD 9:CTS 10:DSR 11:CI
bridge this solder jumper if you want to power the G850 from USB (default:no)
bridge this solder jumper (5V) for use with G850 !
500mA polyfuse would be fine
0R (=bridge) is acceptable here
Don't forget to download FTProg from FTDI and - invert TXD, RXD, RTS, CTS ! - configure CBUS0 as RXLED - configure CBUS1 as TXLED - NEVER SET TO EXTERNAL OSCILLATOR !!!

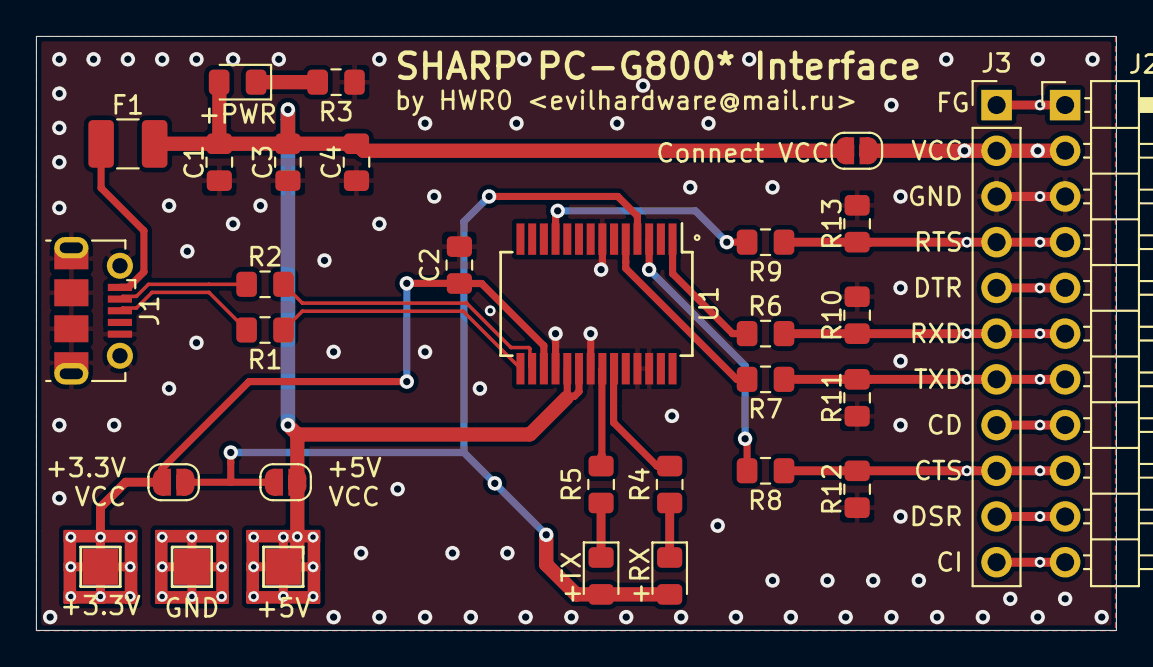
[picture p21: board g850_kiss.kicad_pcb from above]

Board: 2 copper layers, 60.0 x 33.0 mm, 31 parts (0 on the bottom side), 28 nets.

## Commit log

2020-08-10 First Commit
    upload of G850 K.I.S.S. Interface and 11 to 15pin adapter
    [Sharp_11pin_to_15pin_Adapter-B_Cu.gbr, Sharp_11pin_to_15pin_Adapter-B_Mask.gbr, Sharp_11pin_to_15pin_Adapter-B_Paste.gbr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]
2020-08-24 Added E500/PC-1600 USB to Serial Adapter
    [PC1600SIO-B_Cu.gbr, PC1600SIO-B_Mask.gbr, PC1600SIO-B_Paste.gbr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]
